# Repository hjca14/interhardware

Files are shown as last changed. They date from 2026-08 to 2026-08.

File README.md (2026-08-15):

# InterBridge Hardware

Hardware do **InterBridge**, uma ponte entre uma linha analógica compatível com
telefone convencional e um aplicativo móvel, por Wi-Fi.

## Escopo deste repositório

Este repositório concentrará o projeto eletrônico no KiCad, as bibliotecas
locais, as decisões de engenharia, as referências e, futuramente, os artefatos
de fabricação (BOM, Gerbers e dados de montagem). O firmware e o aplicativo
móvel não fazem parte deste repositório.

O projeto está em **fase inicial de pesquisa e prototipagem**. Ainda não há um
esquemático ou uma PCB aprovados. Consulte os [requisitos](docs/REQUIREMENTS.md),
a [arquitetura](docs/ARCHITECTURE.md) e as
[decisões registradas](docs/decisions/).

## Arquitetura proposta

- entrada de linha analógica em um conector **RJ11 LINE**;
- saída **RJ11 PHONE** em paralelo/pass-through para preservar o telefone ou
  interfone físico;
- proteção de linha e interface FXO/DAA, preferencialmente baseada no conjunto
  **Si3050 + Si3019**;
- módulo **ESP32-C3** para controle, processamento e conectividade Wi-Fi;
- possibilidade futura de saída por relé para instalações nas quais a abertura
  do portão usa um contato separado.

O pass-through LINE → PHONE deverá ser passivo/fail-safe sempre que a validação
elétrica da instalação permitir, de modo que o aparelho físico continue
funcionando mesmo com o InterBridge sem alimentação.

## Princípios de desenvolvimento

- A seção de telefonia será derivada de um **reference design oficial e
  validado da Skyworks para Si3050 + Si3019**, incluindo as recomendações de BOM
  e layout aplicáveis. Não serão criados valores elétricos, pinagens, footprints
  ou circuitos por suposição.
- Datasheets, reference designs e demais materiais de terceiros serão
  referenciados, e não copiados para o repositório sem que sua licença permita e
  sem necessidade clara.
- Segurança elétrica, isolamento, proteção contra surtos e os requisitos de uma
  futura homologação pela Anatel devem ser considerados desde o início, antes
  da fabricação ou conexão a uma instalação real.
- Arquivos-fonte do KiCad e bibliotecas locais devem ser versionados; saídas de
  fabricação serão geradas de forma reproduzível quando o projeto estiver
  validado.

## Estrutura

```text
kicad/                    fontes do projeto KiCad
docs/                     arquitetura, requisitos e documentação
  decisions/              Architecture Decision Records (ADRs)
  reference-designs/      notas e links para projetos de referência
libraries/
  symbols/                símbolos KiCad mantidos pelo projeto
  footprints/             footprints KiCad mantidos pelo projeto
manufacturing/
  gerbers/                 saídas para fabricação da PCB
  bom/                     listas de materiais
  assembly/                dados e instruções de montagem
```

As pastas inicialmente vazias contêm apenas `.gitkeep`. Nenhum circuito
fictício foi criado para preenchê-las.

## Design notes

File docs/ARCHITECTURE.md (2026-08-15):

# Arquitetura do sistema

## Visão de alto nível

```text
LINE RJ11
  |
  +------------------------------------------> PHONE RJ11
  |
  +--> proteção / DAA --> Si3019 <isolamento> Si3050 --> ESP32-C3
                                                        |
                                                        +--> Wi-Fi
                                                        |
                                                        +--> saída por relé (opcional/futura)
```

O diagrama representa apenas os blocos funcionais; ele **não é um circuito** e
não define pinagens, valores, footprints, componentes de proteção nem a solução
de isolamento. Esses detalhes só serão incorporados ao esquemático a partir da
documentação oficial aplicável e depois de revisão técnica.

## Caminho telefônico

O conector LINE recebe a linha analógica. Um ramo segue para a interface
telefônica FXO/DAA planejada em torno do Si3019 (lado da linha) e do Si3050 (lado
do sistema). A implementação desse ramo deverá partir do reference design
oficial da Skyworks, preservando os requisitos de isolamento, proteção, BOM e
layout que forem confirmados durante a pesquisa.

O segundo ramo conecta LINE a PHONE para que o telefone/interfone existente
permaneça disponível. O pass-through deve ser idealmente **passivo e fail-safe**:
a ausência de alimentação ou uma falha do InterBridge não deve, por si só,
interromper o uso do aparelho físico. A topologia exata e seu efeito sobre a
linha ainda precisam de validação em bancada e de uma análise de segurança.

## Controle e conectividade

O módulo ESP32-C3 será responsável pelo controle da interface telefônica e pela
comunicação via Wi-Fi com o restante do sistema. Interfaces digitais, sinais de
áudio, alimentação e firmware ainda serão definidos após a seleção definitiva
dos componentes e a validação da documentação oficial.

Uma saída por relé é uma extensão futura para instalações que disponibilizem um
contato separado de abertura de portão. Ela não faz parte do primeiro circuito
e deverá ter requisitos elétricos e de segurança próprios antes da inclusão.

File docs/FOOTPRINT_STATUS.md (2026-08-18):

# Footprint and PCB status — release-candidate audit

> Current-state summary. The historical preliminary BOM remains at `manufacturing/bom/BOM_PRELIMINARY.md`; it predates the routed PCB and is not the procurement BOM.

## Current metrics

| Metric | Result |
|---|---:|
| Physical schematic components | 65 |
| PCB footprints | 65 |
| Missing / duplicate references | 0 / 0 |
| Missing footprint assignments | 0 |
| Top / bottom components | 65 / 0 |
| Copper layers | 2 |
| Board thickness | 1.6 mm |
| Final BOM lines | 45 |
| LOCKED / EQUIVALENT_ALLOWED / VERIFY_BEFORE_ORDER lines | 16 / 29 / 0 |
| DNP | 0 |

`tools/release_inventory.py` performs the repeatable reference-parity, duplicate, footprint-presence, and side checks and writes `manufacturing/reports/COMPONENT_INVENTORY.csv`.

## Current footprint decisions

* U1 uses the project SI3019 QFN-20 footprint plus exposed pad 21; U2 uses the project SI3050 QFN-24 footprint plus exposed pad 25.
* J1 is one physical custom Amphenol RJE0166002 dual 6P6C footprint with 12 electrical pads. `_1` is LINE and `_2` is PHONE; central contacts 3/4 are RING/TIP.
* L1 uses the project VLS3012 footprint. U3 remains ESP32-C3-WROOM-02 (integrated PCB antenna), not -02U.
* The current USB connector reference is J2 and its locked MPN is GCT USB4105-GF-A-060. Older text referring to J4 is superseded; the audit did not reannotate the design.
* D1 is locked as onsemi MDB6S (1 A, 600 V) in the existing `Package_SO:TSSOP-4_4.4x5mm_P4mm` footprint. The footprint and mechanical courtyard exist. No separately validated visible 3D rendering is available for release review; assembly therefore relies on the footprint dimensions rather than 3D rendering.

## Release evidence and limitations

The PCB is routed. The user reports ERC 0 errors / 0 warnings, DRC 0 violations, and all nets routed. `kicad-cli` is absent here, so those results were not independently reproduced and manufacturing outputs were not generated. See `manufacturing/reports/RELEASE_VALIDATION.md` and `manufacturing/reports/PCB_RELEASE_AUDIT.md`.

The former count of 44 `TBD` components is no longer a blocker: those commodity parts now have electrical sourcing constraints and are `EQUIVALENT_ALLOWED`; the transistor families are similarly specified without inventing a manufacturer. There are zero component-ordering blockers.

The user reviewed the antenna keepout warning locally and visually confirmed the actual region is empty of copper, tracks, vias, and components. A final human DRC review is still required before manufacturing.

**Release candidate BOM and procurement classification are complete with zero component-ordering blockers; final human manufacturing approval is still required.**

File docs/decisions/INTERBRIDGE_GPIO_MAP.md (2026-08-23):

# InterBridge — Mapeamento de GPIO / interfaces

> Estado atual do hardware baseado no `interhardware.kicad_sch` e no
> `interhardware.kicad_pcb` da branch `main`.
> Este documento descreve o mapeamento físico previsto entre o ESP32-C3-WROOM-02 (U3) e os principais blocos da placa.

## 1. ESP32-C3 ↔ Si3050

| Componente / pino da placa | ESP32-C3 GPIO | Pad físico do módulo U3 | Função prevista | Direção vista do ESP |
|---|---:|---:|---|---|
| U2 / PCLK | GPIO0 | 18 | PCM master/input clock para o Si3050 | ESP → Si3050 |
| U2 / FSYNC | GPIO1 | 17 | PCM frame sync | ESP → Si3050 |
| U2 / SDO | GPIO2 | 16 | SPI data output do Si3050 (MISO no ESP), com pull-up externo R56 de 10 kΩ para 3,3 V | Si3050 → ESP |
| U2 / DTX | GPIO3 | 15 | PCM data transmit do Si3050 | Si3050 → ESP |
| U2 / DRX | GPIO4 | 3 | PCM data receive do Si3050 | ESP → Si3050 |
| U2 / RESET | GPIO5 | 4 | Reset do Si3050, ativo em nível baixo, com pulldown externo R54 de 10 kΩ para GND | ESP → Si3050 |
| U2 / SCLK | GPIO6 | 5 | SPI clock | ESP → Si3050 |
| U2 / SDI | GPIO7 | 6 | SPI data input do Si3050 (MOSI no ESP) | ESP → Si3050 |
| U2 / RGDT | GPIO8 | 7 | Ring detect do Si3050, saída open-drain com pull-up externo R58 de 4,7 kΩ para 3,3 V | Si3050 → ESP |
| U2 / CS | GPIO10 | 10 | SPI chip select, ativo em nível baixo | ESP → Si3050 |

GPIO9 não está ligado ao Si3050: é o pino `BOOT` do próprio ESP32-C3, reservado para modo ROM download/recuperação (ver seção 6), com pull-up externo R57 de 10 kΩ para 3,3 V.

## 2. Si3050 — sinais fora do barramento PCM/SPI

- `RGDT` (pino 6 do Si3050) está conectado ao **GPIO8** para detecção de ring. É uma saída **open-drain**, **ativa em nível baixo por padrão** (nível baixo = ring detectado), por isso depende do pull-up externo R58 (4,7 kΩ para 3,3 V) descrito na seção 1.
- `AOUT/INT` (pino 7 do Si3050) **não está conectado ao ESP**; permanece apenas no furo/pad de bancada `AOUT1`, sem GPIO associado.
- `RG`, `TGD`, `TGDE` e `SDI_THRU` continuam fora da arquitetura da Rev A (sem uso previsto).
- O polling via SPI dos registradores do Si3050 continua disponível para os demais estados/eventos que não passam por `RGDT`.

## 3. USB, botão e LED

| Componente / sinal | ESP32-C3 GPIO | Pad físico U3 | Função |
|---|---:|---:|---|
| USB D− | GPIO18 | 13 | USB 2.0 D− nativo do ESP32-C3 |
| USB D+ | GPIO19 | 14 | USB 2.0 D+ nativo do ESP32-C3 |
| SW1 / botão de setup | GPIO20 / RXD | 11 | Botão físico de setup/configuração/reset de provisioning conforme firmware |
| D2 / WS2812B DIN via R_LED1 | GPIO21 / TXD | 12 | LED RGB de status / onboarding |

## 4. Alimentação e GND

| Bloco | Alimentação | GND / domínio | Observação |
|---|---|---|---|
| J2 USB-C | VBUS 5 V | GND | Entrada principal de alimentação |
| U4 TPS62162 | 5 V em VIN | GND | Buck para 3,3 V |
| U3 ESP32-C3-WROOM-02 | +3,3 V no pad 1 | GND nos pads 9 e 19 | Domínio digital |
| U2 Si3050 | +3,3 V / alimentação digital conforme schematic | GND | Mesmo domínio digital do ESP |
| U1 Si3019 | domínio line-side | IGND | **Isolado do GND digital** |
| C1/C2 | barreira de isolamento | GND ↔ IGND | Não unir GND e IGND diretamente |

## 5. Requisitos de inicialização do firmware (RESET / modo PCM-SPI)

Esta sequência é responsabilidade do **firmware**; o hardware não a executa sozinho:

1. O firmware deve manter `RESET` (GPIO5) em nível baixo durante toda a configuração inicial do circuito.
2. `SCLK` (GPIO6) deve estar em nível **alto** no instante em que `RESET` sobe — essa condição seleciona o modo PCM/SPI do Si3050. `SCLK` em nível baixo na subida de `RESET` selecionaria o modo GCI, que não é usado nesta Rev A.
3. `PCLK` e `FSYNC` precisam estar estáveis, com relação de frequência fixa entre si, por pelo menos 10 ciclos de `PCLK` antes de o firmware liberar `RESET`.
4. Depois de liberar o reset, o firmware deve aguardar a estabilização do PLL interno do Si3050 antes de configurar os registradores via SPI.

## 6. Recuperação / programação (furos THT de bancada)

Três furos THT existem na placa para gravação/recuperação manual do ESP32-C3. Eles **não são conectores a serem montados no produto final** — são pontos de teste de bancada/fábrica:

| Furo | Sinal | Função |
|---|---|---|
| `BOOT1` | GPIO9 | Strap de boot do ESP32-C3 (modo ROM download quando em GND na subida do reset) |
| `EN1` | `/EN` | Chip enable / reset do ESP32-C3 |
| `GND1` | GND | Referência de terra |

Procedimento manual resumido para entrar em modo de gravação:

`BOOT` em GND → pulso de `EN` em GND → soltar `EN` → soltar `BOOT` → gravar via USB nativo nos GPIO18/19 (D−/D+).

Esse procedimento é usado apenas para a primeira gravação, bancada, fábrica e recuperação. Atualizações normais em campo são feitas via OTA, sem uso destes furos.

## 7. Conector J1 — LINE / PHONE

J1 é um único conector físico Amphenol `RJE0166002`, com dois jacks 6P6C.

| Jack | Contato | Função | Net atual |
|---|---:|---|---|
| LINE (`_1`) | 3 | RING | `Net-(RV1-K)` |
| LINE (`_1`) | 4 | TIP | `Net-(RV1-A)` |
| PHONE (`_2`) | 3 | RING | `Net-(RV1-K)` |
| PHONE (`_2`) | 4 | TIP | `Net-(RV1-A)` |
| LINE / PHONE | 1, 2, 5, 6 | NC | não usados |

Os contatos centrais 3/4 dos dois jacks ficam em pass-through elétrico na placa:
- `RING LINE` ↔ `RING PHONE`
- `TIP LINE` ↔ `TIP PHONE`

O DAA observa/interage com esse par através do circuito line-side, sem interromper o telefone/interfone original. Esta Rev A não tem relé, `DOOR_ACTUATE` nem qualquer forma de abertura física da linha ou da fechadura.

## 8. Resumo para firmware

```text
GPIO0   = PCLK        (PCM, ESP -> Si3050)
GPIO1   = FSYNC       (PCM, ESP -> Si3050)
GPIO2   = SDO         (SPI MISO / Si3050 -> ESP, pull-up externo 10k para 3V3)
GPIO3   = DTX         (PCM Si3050 -> ESP)
GPIO4   = DRX         (PCM ESP -> Si3050)
GPIO5   = RESET       (Si3050 reset, ativo baixo, pulldown externo R54 10k para GND)
GPIO6   = SCLK        (SPI clock, ESP -> Si3050; alto na subida de RESET = modo PCM/SPI)
GPIO7   = SDI         (SPI MOSI / ESP -> Si3050)
GPIO8   = RGDT        (Si3050 -> ESP, ring detect, open-drain ativo baixo, pull-up externo 4k7 para 3V3)
GPIO9   = BOOT        (strap de boot do ESP, modo ROM download/recuperação, pull-up externo 10k para 3V3)
GPIO10  = CS          (SPI chip select, ativo baixo)
GPIO18  = USB D-
GPIO19  = USB D+
GPIO20  = BUTTON
GPIO21  = STATUS LED (WS2812B DIN)
```

`AOUT/INT` do Si3050 não tem GPIO associado nesta Rev A; fica disponível apenas no pad de bancada `AOUT1`.

## 9. Observação de firmware

Os nomes `SDO` e `SDI` acima seguem a nomenclatura do **Si3050**, não a do ESP:
- Si3050 `SDO` = saída do Si3050 = entrada/MISO no ESP.
- Si3050 `SDI` = entrada do Si3050 = saída/MOSI no ESP.

Da mesma forma:
- `DTX` é saída PCM do Si3050.
- `DRX` é entrada PCM do Si3050.
- `RGDT` é saída open-drain do Si3050, ativa em nível baixo por padrão (requer pull-up externo, ver seção 1/2).

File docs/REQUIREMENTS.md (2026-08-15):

# Requisitos iniciais

Este documento registra requisitos de produto ainda sujeitos a refinamento. Os
itens não especificam soluções elétricas; critérios quantitativos serão
adicionados somente com referências adequadas e resultados de validação.

## Funcionais

- **RF-01 — Detecção de chamada:** detectar o sinal de ring da linha.
- **RF-02 — Controle da chamada:** atender e desligar (hangup)
  eletronicamente.
- **RF-03 — Áudio:** suportar áudio bidirecional durante uma chamada.
- **RF-04 — DTMF:** suportar os tons DTMF necessários à operação do interfone.
- **RF-05 — Aparelho em paralelo:** detectar, se tecnicamente viável, quando o
  telefone/interfone físico em paralelo estiver off-hook.
- **RF-06 — Operação sem energia:** manter o telefone/interfone físico
  utilizável quando o InterBridge estiver sem alimentação.
- **RF-07 — Conectividade:** comunicar-se com o sistema móvel por Wi-Fi.
- **RF-08 — Expansão:** permitir avaliar uma futura saída por relé para abertura
  de portão por contato separado.

## Hardware

- **RH-01:** usar conectores identificados como RJ11 LINE e RJ11 PHONE.
- **RH-02:** implementar pass-through LINE → PHONE preferencialmente passivo e
  fail-safe, condicionado à validação elétrica.
- **RH-03:** basear a seção FXO/DAA no reference design oficial selecionado; não
  definir valores, pinagens, footprints ou layout sem fonte verificável.
- **RH-04:** adotar inicialmente um módulo ESP32-C3 para controle e Wi-Fi.
- **RH-05:** manter símbolos e footprints específicos do projeto em bibliotecas
  versionadas e rastreáveis às fontes técnicas.
- **RH-06:** prever pontos de teste suficientes para validação segura dos blocos,
  a serem definidos durante o projeto do esquemático.

## Segurança

- **RS-01:** identificar as tensões, correntes, transientes e condições de falha
  aplicáveis à linha antes de dimensionar a interface.
- **RS-02:** definir isolamento e distâncias de segurança com base em normas e
  documentação técnica aplicáveis, sem pressupor valores.
- **RS-03:** incluir proteção contra surtos e eventos da linha de acordo com o
  reference design validado e os requisitos da instalação-alvo.
- **RS-04:** realizar revisão de segurança antes de conectar protótipos a uma
  linha real.
- **RS-05:** considerar desde o projeto os requisitos aplicáveis a uma futura
  homologação Anatel.
- **RS-06:** documentar limitações, riscos residuais e procedimentos seguros de
  teste.

## Fabricação

- **RM-01:** manter os fontes `.kicad_pro`, `.kicad_sch`, `.kicad_pcb` e as
  bibliotecas locais sob controle de versão.
- **RM-02:** gerar BOM, Gerbers e dados de montagem de maneira reproduzível a
  partir de uma revisão identificada do projeto.
- **RM-03:** registrar fabricante, código exato e alternativas aprovadas dos
  componentes na BOM.
- **RM-04:** executar ERC, DRC e revisão dos arquivos de fabricação antes de
  liberar uma placa.
- **RM-05:** validar disponibilidade, encapsulamento e lifecycle dos componentes
  antes da compra ou montagem.

## Ainda em investigação

- seleção definitiva entre Si3050 + Si3019, Le9641 e outras alternativas;
- disponibilidade, condições de aquisição e status de ciclo de vida dos CIs;
- compatibilidade da solução com as variações de linhas de interfone/telefone
  encontradas no Brasil;
- mecanismo e confiabilidade da detecção de off-hook do aparelho em paralelo;
- requisitos de áudio, níveis, codecs e tratamento de eco;
- requisitos detalhados de alimentação e consumo;
- topologia, classificação e interface da eventual saída por relé;
- normas técnicas, ensaios e modalidade de homologação Anatel aplicáveis;
- estratégia de testes de bancada e equipamentos necessários;
- critérios quantitativos de proteção, isolamento e layout.

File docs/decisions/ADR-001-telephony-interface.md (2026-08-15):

# ADR-001 — Interface de telefonia

- **Status:** provisoriamente aceito
- **Data:** 2026-08-15

## Contexto

O InterBridge precisa interagir com uma linha analógica compatível com telefone
convencional, detectando chamadas, controlando o estado on-hook/off-hook e
transportando áudio e DTMF. Essa interface envolve requisitos de linha,
isolamento, proteção e layout que não devem ser definidos por tentativa ou
suposição.

Nesta fase, é especialmente importante escolher uma solução que possa ser
reproduzida e revisada a partir de documentação técnica suficiente.

## Decisão

Preferir provisoriamente o conjunto **Si3050 + Si3019** para a interface FXO/DAA.
A preferência se deve à documentação pública e ao conjunto de materiais oficiais
disponíveis para avaliação — reference design, BOM, orientações de layout, placa
de avaliação (EVB) e guias relacionados.

O esquemático não será desenhado até que esses documentos sejam coletados das
fontes oficiais, revisados e transformados em requisitos rastreáveis. O projeto
não inferirá valores elétricos, pinagens ou footprints.

## Alternativas consideradas

- **Le9641:** permanece como alternativa a pesquisar, especialmente quanto a
  documentação, disponibilidade e adequação à arquitetura.
- **Outras famílias FXO/DAA:** poderão ser avaliadas com os mesmos critérios de
  documentação, segurança, disponibilidade, custo e possibilidade de validação.

## Consequências

- A primeira pesquisa e os testes de bancada serão orientados ao Si3050 +
  Si3019.
- A implementação deverá seguir o reference design oficial e suas recomendações
  aplicáveis, em vez de criar uma seção telefônica arbitrária.
- A origem e a revisão de cada documento usado deverão ser registradas em
  `docs/reference-designs/`; arquivos de terceiros não serão redistribuídos sem
  licença ou necessidade.
- A decisão **pode mudar após testes de bancada**, revisão de segurança,
  confirmação de disponibilidade ou descoberta de requisitos incompatíveis.

## Critérios para reavaliação

- resultados dos testes de ring, hook, áudio, DTMF e operação em paralelo;
- conformidade com requisitos de isolamento e proteção aplicáveis;
- qualidade e atualidade da documentação oficial;
- disponibilidade e ciclo de vida dos componentes;
- complexidade de fabricação e suporte à validação/homologação.

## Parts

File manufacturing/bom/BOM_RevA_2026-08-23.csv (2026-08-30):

Refs | Qty | Value | Manufacturer | Base_MPN | Approved_Sourcing_MPN | Description | Tolerance | Power_Rating | Voltage_Rating | Dielectric_or_Type | Package | Footprint | Procurement_Class | Notes
C1,C2 | 2 | 33pF | Murata | GA342A1XGF330JW31L |  | Safety isolation capacitor | ±5% | N/A | 250VAC | X1/Y2 safety ceramic | 1808 | Capacitor_SMD:C_1808_4520Metric | LOCKED | Isolation barrier; exact safety-certified MPN.
C3 | 1 | 3.9nF | GENERIC | GENERIC | CC1206MRX7RYBB392 | DAA high-voltage capacitor | ±20% | N/A | >=250VDC | X7R ceramic | 1206 | Capacitor_SMD:C_1206_3216Metric | EQUIVALENT_ALLOWED | EVB specifies 250V, 20%, X7R; PCB package is larger than EVB 0805.
C4 | 1 | 1uF | Panasonic | EEE-1HA010NR |  | Aluminum electrolytic capacitor | ±20% | N/A | 50V | Aluminum electrolytic | 4x5.4mm SMD | Capacitor_SMD:CP_Elec_4x5.4 | LOCKED
C5,C6,C50,C51 | 4 | 0.1uF | GENERIC | GENERIC | C0603C104M4RAC7411 | DAA bypass capacitor | ±20% | N/A | >=16VDC | X7R ceramic | 0603 | Capacitor_SMD:C_0603_1608Metric | EQUIVALENT_ALLOWED | EVB BOM: 16V X7R 20%.
C7 | 1 | 2.7nF | GENERIC | GENERIC | GCM188R71H272MA37D | DAA capacitor | ±20% | N/A | >=50VDC | X7R ceramic | 0603 | Capacitor_SMD:C_0603_1608Metric | EQUIVALENT_ALLOWED | EVB BOM: 50V X7R 20%.
C8,C9 | 2 | 680pF | Murata | GA342QR7GF681KW01L |  | Safety isolation capacitor | ±10% | N/A | 250VAC | X1/Y2 safety ceramic | 1808 | Capacitor_SMD:C_1808_4520Metric | LOCKED | Isolation barrier; exact safety-certified MPN.
C10 | 1 | 0.01uF | GENERIC | GENERIC | C0603C103M4RACTU | DAA capacitor | ±20% | N/A | >=16VDC | X7R ceramic | 0603 | Capacitor_SMD:C_0603_1608Metric | EQUIVALENT_ALLOWED | EVB BOM specifies X7R, 20%; 16V minimum sourcing constraint for low-voltage D...
C30,C31 | 2 | 120pF | GENERIC | GENERIC | HHV1206R7121K102NSLJ | DAA high-voltage capacitor | ±10% | N/A | >=250VDC | X7R ceramic | 1206 | Capacitor_SMD:C_1206_3216Metric | EQUIVALENT_ALLOWED | EVB specifies 250V, 10%, X7R; PCB package is larger than EVB 0805.
C52 | 1 | 0.1uF | GENERIC | GENERIC | 0603ZC104KAT2A | Digital decoupling capacitor | ±10% | N/A | >=10VDC | X7R ceramic | 0603 | Capacitor_SMD:C_0603_1608Metric | EQUIVALENT_ALLOWED | Digital-domain decoupling, not an EVB line-side capacitor.
C75 | 1 | 10uF | GENERIC | GENERIC | TCC0805X5R106M250FT | TPS62162 input capacitor | ±20% | N/A | >=25VDC | X7R or X5R ceramic | 0805 | Capacitor_SMD:C_0805_2012Metric | EQUIVALENT_ALLOWED | Voltage rating covers TPS62162 17V maximum input; account for DC-bias derating.
C76 | 1 | 22uF | GENERIC | GENERIC | GRM21BR60J226ME39L | TPS62162 output capacitor | ±20% | N/A | >=6.3VDC | X7R or X5R ceramic | 0805 | Capacitor_SMD:C_0805_2012Metric | EQUIVALENT_ALLOWED | 3.3V output; account for DC-bias derating.
D1 | 1 | MDB6S | onsemi | MDB6S |  | 1 A, 600 V single-phase bridge rectifier | N/A | N/A | 600 V repetiti... |  | TSSOP-4 / MDBxS | Package_SO:TSSOP-4_4.4x5mm_P4mm | LOCKED | Meets/exceeds the reference-design requirement of 0.8 A / 400 V.
D2 | 1 | WS2812B-2020 | Worldsemi | WS2812B-2020 |  | Addressable RGB LED | N/A | N/A | 5V nominal | Integrated LED/... | PLCC-4 2.0x2.0mm | LED_SMD:LED_WS2812B-2020_PLCC4_2.0x2.0mm | LOCKED
FB1,FB2,FB203,FB204 | 4 | 600 Ohm | Murata | BLM18AG601SN1 | BLM18AG601SN1D | Ferrite bead, 600 ohm at 100MHz | ±25% impedance | N/A | 50VDC | Fe... | 0603 | Inductor_SMD:L_0603_1608Metric | LOCKED
J1 | 1 | RJE0166002 | Amphenol Communications Solutions | RJE0166002 |  | Dual 6P6C right-angle jack | N/A | N/A | N/A | THT connector | Dual 6P6C right-angle THT | interbridge_telephony:AMPHENOL_RJE0166002 | LOCKED | One physical part; _1 LINE, _2 PHONE; contacts 3 RING / 4 TIP.
J2 | 1 | USB4105-GF-A-060 | GCT | USB4105-GF-A-060 |  | USB Type-C USB2 receptacle | N/A | N/A | 5V | 16-contact h... | USB-C | Connector_USB:USB_C_Receptacle_GCT_USB4105-xx-A_16P_TopMnt_Horizontal | LOCKED | Current designator is J2 (earlier documentation called it J4).
L1 | 1 | 2.2uH | TDK | VLS3012HBX-2R2M-N |  | Shielded power inductor | ±20% | Isat >=2.84A | N/A | Wirewound shiel... | VLS3012 | interbridge_telephony:IND_VLS3012HBX-2R2M-N | LOCKED
Q1,Q3 | 2 | MMBTA42 | GENERIC | MMBTA42 |  | High-voltage NPN transistor | N/A | SOT-23 dissipation; verify asse... |  |  | SOT-23 | Package_TO_SOT_SMD:SOT-23 | EQUIVALENT_ALLOWED | Reference design uses MMBTA42 family; no manufacturer frozen. Approved sourcing brand: UMW, provided ratings/package/pinout match.
Q2 | 1 | MMBTA92 | GENERIC | MMBTA92 |  | High-voltage PNP transistor | N/A | SOT-23 dissipation; verify asse... |  |  | SOT-23 | Package_TO_SOT_SMD:SOT-23 | EQUIVALENT_ALLOWED | Reference design uses MMBTA92 family; no manufacturer frozen. Approved sourcing brand: UMW, provided ratings/package/pinout match.
Q4,Q5 | 2 | MMBTA06 | GENERIC | MMBTA06 |  | NPN transistor | N/A | SOT-23 dissipation; verify assembly thermal ... |  |  | SOT-23 | Package_TO_SOT_SMD:SOT-23 | EQUIVALENT_ALLOWED | Reference design uses MMBTA06 family; no manufacturer frozen. Approved sourcing brand: UMW, provided ratings/package/pinout match.
R1 | 1 | 1.07k Ohm | GENERIC | GENERIC | AC1206FR-071K07L | Thick-film resistor | ±1% | >=0.5W | >=200V | Thick-film | 1206 | Resistor_SMD:R_1206_3216Metric | EQUIVALENT_ALLOWED | DAA EVB requires 1/2W.
R2 | 1 | 150 Ohm | GENERIC | GENERIC | RC0603FR-07150RL | Thick-film resistor | ±1% | >=0.0625W | >=25V | Thick-film | 0603 | Resistor_SMD:R_0603_1608Metric | EQUIVALENT_ALLOWED | DAA EVB requires 1/16W.
R3 | 1 | 3.65k Ohm | GENERIC | GENERIC | AC1206FR-073K65L | Thick-film resistor | ±1% | >=0.5W | >=200V | Thick-film | 1206 | Resistor_SMD:R_1206_3216Metric | EQUIVALENT_ALLOWED | DAA EVB requires 1/2W.
R4 | 1 | 2.49k Ohm | GENERIC | GENERIC | TC0650F2491T5J | Thick-film resistor | ±1% | >=0.5W | >=200V | Thick-film | 1206 | Resistor_SMD:R_1206_3216Metric | EQUIVALENT_ALLOWED | DAA EVB requires 1/2W.
R5,R6 | 2 | 100k Ohm | GENERIC | GENERIC | 0603WAJ0104T5E | Thick-film resistor | ±5% | >=0.0625W | >=25V | Thick-film | 0603 | Resistor_SMD:R_0603_1608Metric | EQUIVALENT_ALLOWED | DAA EVB requires 1/16W.
R9 | 1 | 1M Ohm | GENERIC | GENERIC | AC0603JR-071ML | Thick-film resistor | ±5% | >=0.1W | >=50V | Thick-film | 0603 | Resistor_SMD:R_0603_1608Metric | EQUIVALENT_ALLOWED | DAA bias resistor.
R10 | 1 | 536 Ohm | GENERIC | GENERIC | RC1206FR-07536RL | Thick-film resistor | ±1% | >=0.25W | >=200V | Thick-film | 1206 | Resistor_SMD:R_1206_3216Metric | EQUIVALENT_ALLOWED | DAA EVB requires 1/4W.
R11 | 1 | 73.2 Ohm | GENERIC | GENERIC | RS-06K73R2FT | Thick-film resistor | ±1% | >=0.5W | >=200V | Thick-film | 1206 | Resistor_SMD:R_1206_3216Metric | EQUIVALENT_ALLOWED | DAA EVB requires 1/2W.
R12,R13 | 2 | 56.2 Ohm | GENERIC | GENERIC | RTT0356R2FTP | Thick-film resistor | ±1% | >=0.0625W | >=25V | Thick-film | 0603 | Resistor_SMD:R_0603_1608Metric | EQUIVALENT_ALLOWED | DAA EVB requires 1/16W.
R30,R32 | 2 | 15M Ohm | GENERIC | GENERIC | HV06W4J0156T5E | Thick-film resistor | ±5% | >=0.125W | >=200V | Thick-film | 1206 | Resistor_SMD:R_1206_3216Metric | EQUIVALENT_ALLOWED | High-value DAA line-side resistor; EVB requires 1/8W.
R31,R33 | 2 | 5.1M Ohm | GENERIC | GENERIC | 1206W4J0515T5E | Thick-film resistor | ±5% | >=0.125W | >=200V | Thick-film | 1206 | Resistor_SMD:R_1206_3216Metric | EQUIVALENT_ALLOWED | High-value DAA line-side resistor; EVB requires 1/8W.
R52,R53 | 2 | 47k Ohm | GENERIC | GENERIC | 0603WAJ0473T5E | Thick-film resistor | ±5% | >=0.0625W | >=25V | Thick-film | 0603 | Resistor_SMD:R_0603_1608Metric | EQUIVALENT_ALLOWED | DAA/digital control resistors.
R54,R55,R56,R57,R_BO1 | 5 | 10k Ohm | GENERIC | GENERIC | RC0603FR-0710KL | Thick-film resistor | ±1% | >=0.1W | >=25V | Thick-film | 0603 | Resistor_SMD:R_0603_1608Metric | EQUIVALENT_ALLOWED | 10k digital bias resistors. R54 = Si3050 RESET pulldown to GND; R56 = GPIO2/SDO pull-up to 3.3V; R57 = GPIO9/BOOT pull-up to 3.3V; R55 and R_BO1 retain their existing digital bias functions.
R58 | 1 | 4.7k Ohm | GENERIC | GENERIC |  | RGDT open-drain pull-up resistor | ±1% | >=0.1W | >=25V | Thick-film | 0603 | Resistor_SMD:R_0603_1608Metric | EQUIVALENT_ALLOWED | Pull-up from Si3050 RGDT / ESP32-C3 GPIO8 to +3.3V.
R71,R72 | 2 | 5.1k Ohm | GENERIC | GENERIC | 0603WAF5101T5E | Thick-film resistor | ±1% | >=0.1W | >=25V | Thick-film | 0603 | Resistor_SMD:R_0603_1608Metric | EQUIVALENT_ALLOWED | USB-C CC resistors.
R73,R74 | 2 | 22 Ohm | GENERIC | GENERIC | 0603WAF220JT5E | Thick-film resistor | ±1% | >=0.1W | >=25V | Thick-film | 0603 | Resistor_SMD:R_0603_1608Metric | EQUIVALENT_ALLOWED | USB data series resistors.
R75 | 1 | 100k Ohm | GENERIC | GENERIC | CQ03WAF1003T5E | Thick-film resistor | ±1% | >=0.1W | >=25V | Thick-film | 0603 | Resistor_SMD:R_0603_1608Metric | EQUIVALENT_ALLOWED | TPS62162 control/bias resistor.
RV1 | 1 | P3100SBL | Littelfuse | P3100SBL | P3100SBLRP | Bidirectional SIDACtor | N/A | N/A | 275V standoff | SIDACtor, not... | DO-214AA / SMB | Diode_SMD:D_SMB | LOCKED
SW1 | 1 | B3U-1000P | Omron | B3U-1000P |  | Normally-open tactile switch | N/A | N/A | N/A | Momentary SPST-NO | SMD | Button_Switch_SMD:SW_SPST_B3U-1000P | LOCKED
U1 | 1 | SI3019-F-FM | Skyworks Solutions | SI3019-F-FM |  | Line-side DAA IC | N/A | N/A | Per datasheet | QFN-20 + exposed... | QFN-20-1EP | interbridge_telephony:3019-F-FM-QFN40P300X300X90-21N | LOCKED | Exposed electrical pad 21 maps to IGND.
U2 | 1 | SI3050-E1-FM | Skyworks Solutions | SI3050-E1-FM |  | System-side DAA IC | N/A | N/A | Per datasheet | QFN-24 + expo... | QFN-24-1EP | interbridge_telephony:3050-E1-FM-QFN50P400X400X80-25N | LOCKED | Exposed electrical pad 25 maps to GND.
U3 | 1 | ESP32-C3-WROOM-02 | Espressif Systems | ESP32-C3-WROOM-02 | ESP32-C3-WROOM-02-N4 OR ESP32-C3-WROOM-02-H4 | Wi-Fi/BLE module with PCB antenna | N/A | N/A | 3.0-3.6V『... |  | Module | RF_Module:ESP32-C3-WROOM-02 | LOCKED | 4 MB flash, integrated PCB antenna. N4 and H4 are both approved; do not use -02U.
U4 | 1 | TPS62162DSG | Texas Instruments | TPS62162DSG | TPS62162DSGT | 3.3V 1A step-down converter | N/A | N/A | 3-17V input | WSON-8 ... | WSON-8-1EP DSG | Package_SON:Texas_DSG0008A_WSON-8-1EP_2x2mm_P0.5mm_EP0.9x1.6... | LOCKED
Z1 | 1 | 43V | onsemi | MMSZ43T1G |  | 43V Zener diode | ±5% | 500mW | 43V nominal | Zener | SOD-123 | Diode_SMD:D_SOD-123 | LOCKED
C_LED1 | 1 | 0.1uF | GENERIC | GENERIC | 0603ZC104KAT2A | LED local decoupling capacitor | ±10% | N/A | >=10VDC | X7R ceramic | 0603 | Capacitor_SMD:C_0603_1608Metric | EQUIVALENT_ALLOWED
R_LED1 | 1 | 330 Ohm | GENERIC | GENERIC | 0603WAF3300T5E | Thick-film resistor | ±1% | >=0.1W | >=25V | Thick-film | 0603 | Resistor_SMD:R_0603_1608Metric | EQUIVALENT_ALLOWED | LED series resistor.

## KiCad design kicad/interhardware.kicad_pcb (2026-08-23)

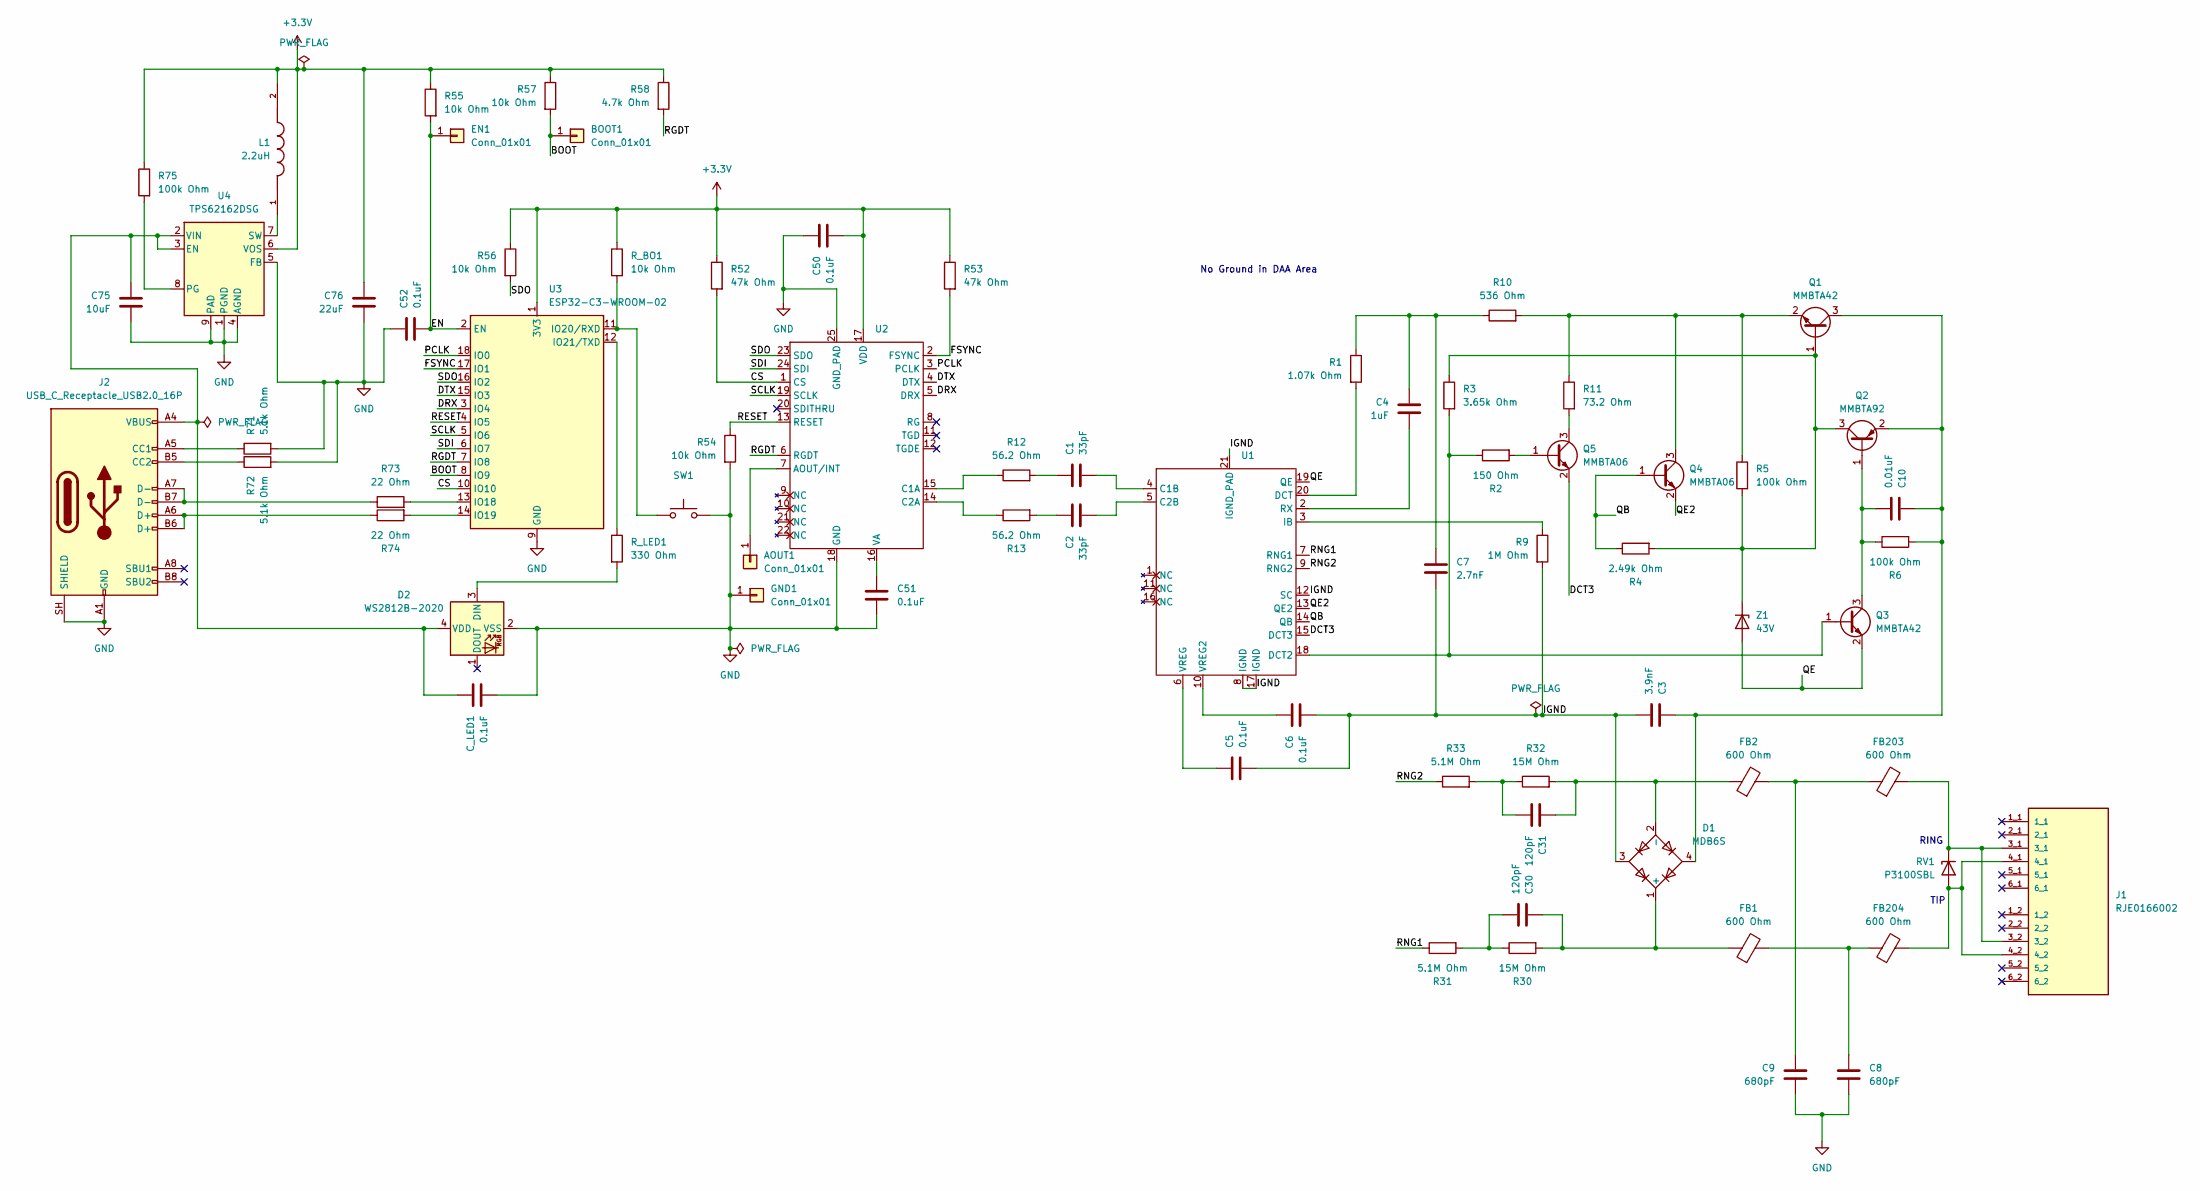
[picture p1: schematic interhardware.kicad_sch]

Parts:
AOUT1: Conn_01x01; PinHeader_1x01_P2.54mm_Vertical
BOOT1: Conn_01x01; PinHeader_1x01_P2.54mm_Vertical
C1, C2: 33pF; C_1808_4520Metric; MPN GA342A1XGF330JW31L
C3: 3.9nF; C_1206_3216Metric; MPN GENERIC
C4: 1uF; CP_Elec_4x5.4; MPN EEE-1HA010NR
C5, C6, C50, C51, C52: 0.1uF; C_0603_1608Metric; MPN GENERIC
C7: 2.7nF; C_0603_1608Metric; MPN GENERIC
C8, C9: 680pF; C_1808_4520Metric; MPN GA342QR7GF681KW01L
C10: 0.01uF; C_0603_1608Metric; MPN GENERIC
C30, C31: 120pF; C_1206_3216Metric; MPN GENERIC
C75: 10uF; C_0805_2012Metric; MPN GENERIC
C76: 22uF; C_0805_2012Metric; MPN GENERIC
C_LED1: 0.1uF; C_0603_1608Metric; MPN GENERIC
D1: MDB6S; TSSOP-4_4.4x5mm_P4mm; MPN MDB6S
D2: WS2812B-2020; LED_WS2812B-2020_PLCC4_2.0x2.0mm; MPN WS2812B-2020
EN1: Conn_01x01; PinHeader_1x01_P2.54mm_Vertical
FB1, FB2, FB203, FB204: 600 Ohm; L_0603_1608Metric; MPN BLM18AG601SN1
GND1: Conn_01x01; PinHeader_1x01_P2.54mm_Vertical
J1: RJE0166002; AMPHENOL_RJE0166002; PARTREV A
J2: USB_C_Receptacle_USB2.0_16P; USB_C_Receptacle_GCT_USB4105-xx-A_16P_TopMnt_Horizontal; MPN USB4105-GF-A-060
L1: 2.2uH; IND_VLS3012HBX-2R2M-N; PARTREV N/A
Q1, Q3: MMBTA42; SOT-23; MPN MMBTA42
Q2: MMBTA92; SOT-23; MPN MMBTA92
Q4, Q5: MMBTA06; SOT-23; MPN MMBTA06
R1: 1.07k Ohm; R_1206_3216Metric; MPN GENERIC
R2: 150 Ohm; R_0603_1608Metric; MPN GENERIC
R3: 3.65k Ohm; R_1206_3216Metric; MPN GENERIC
R4: 2.49k Ohm; R_1206_3216Metric; MPN GENERIC
R5, R6, R75: 100k Ohm; R_0603_1608Metric; MPN GENERIC
R9: 1M Ohm; R_0603_1608Metric; MPN GENERIC
R10: 536 Ohm; R_1206_3216Metric; MPN GENERIC
R11: 73.2 Ohm; R_1206_3216Metric; MPN GENERIC
R12, R13: 56.2 Ohm; R_0603_1608Metric; MPN GENERIC
R30, R32: 15M Ohm; R_1206_3216Metric; MPN GENERIC
R31, R33: 5.1M Ohm; R_1206_3216Metric; MPN GENERIC
R52, R53: 47k Ohm; R_0603_1608Metric; MPN GENERIC
R54, R55, R56, R57: 10k Ohm; R_0603_1608Metric; MPN GENERIC
R58: 4.7k Ohm; R_0603_1608Metric; MPN GENERIC
R71, R72: 5.1k Ohm; R_0603_1608Metric; MPN GENERIC
R73, R74: 22 Ohm; R_0603_1608Metric; MPN GENERIC
RV1: P3100SBL; D_SMB; MPN P3100SBL
R_BO1: 10k Ohm; R_0603_1608Metric; MPN GENERIC
R_LED1: 330 Ohm; R_0603_1608Metric; MPN GENERIC
SW1: B3U-1000P; SW_SPST_B3U-1000P; MPN B3U-1000P
U1: 3019-F-FM-QFN40P300X300X90-21N
U2: 3050-E1-FM-QFN50P400X400X80-25N
U3: ESP32-C3-WROOM-02; MPN ESP32-C3-WROOM-02
U4: TPS62162DSG; Texas_DSG0008A_WSON-8-1EP_2x2mm_P0.5mm_EP0.9x1.6mm_ThermalV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; MPN TPS62162DSG
Z1: 43V; D_SOD-123; MPN MMSZ43T1G

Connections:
+3.3V: C50.2, C76.1, L1.2, R52.1, R53.1, R55.1, R56.1, R57.1, R58.1, R75.1, R_BO1.1, U2.17 (VDD), U3.1 (3V3), U4.6 (VOS)
/BOOT: BOOT1.1 (Pin_1_1), R57.2, U3.8 (IO9)
/CS: R52.2, U2.1 (CS), U3.10 (IO10)
/DCT3: Q5.2 (E), U1.15 (DCT3)
/DRX: U2.5 (DRX), U3.3 (IO4)
/DTX: U2.4 (DTX), U3.15 (IO3)
/EN: C52.2, EN1.1 (Pin_1_1), R55.2, U3.2 (EN)
/FSYNC: R53.2, U2.2 (FSYNC), U3.17 (IO1)
/IGND: C3.2, C5.2, C6.2, C7.2, D1.3, R9.2, U1.8 (IGND), U1.12 (SC), U1.17 (IGND), U1.21 (IGND_PAD)
/PCLK: U2.3 (PCLK), U3.18 (IO0)
/QB: Q4.1 (B), R4.1, U1.14 (QB)
/QE: Q3.2 (E), U1.19 (QE), Z1.2 (A)
/QE2: Q4.2 (E), U1.13 (QE2)
/RESET: R54.1, U2.13 (RESET), U3.4 (IO5)
/RGDT: R58.2, U2.6 (RGDT), U3.7 (IO8)
/RNG1: R31.1, U1.7 (RNG1)
/RNG2: R33.1, U1.9 (RNG2)
/SCLK: U2.19 (SCLK), U3.5 (IO6)
/SDI: U2.24 (SDI), U3.6 (IO7)
/SDO: R56.2, U2.23 (SDO), U3.16 (IO2)
GND: C8.2, C9.2, C50.1, C51.2, C52.1, C75.2, C76.2, C_LED1.2, D2.2 (VSS), GND1.1 (Pin_1_1), J2.A1 (GND), J2.A12 (GND), J2.B1 (GND), J2.B12 (GND), J2.SH (SHIELD), R54.2, R71.2, R72.2, SW1.2, U2.18 (GND), U2.25 (GND_PAD), U3.9 (GND), U3.19 (GND), U4.1 (PGND), U4.4 (AGND), U4.5 (FB), U4.9 (PAD)
unnamed: AOUT1.1 (Pin_1_1), U2.7 (AOUT/INT)
unnamed: C1.1, R12.2
unnamed: C2.1, R13.2
unnamed: C4.1, C7.1, R1.1, R10.1
unnamed: C8.1, FB1.2, FB204.1
unnamed: C9.1, FB2.2, FB203.1
unnamed: C30.2, R30.1, R31.2
unnamed: C31.2, R32.1, R33.2
unnamed: C30.1, D1.1 (+), FB1.1, R30.2
unnamed: C31.1, D1.2 (-), FB2.1, R32.2
unnamed: D2.3 (DIN), R_LED1.2
unnamed: C75.1, C_LED1.1, D2.4 (VDD), J2.A4 (VBUS), J2.A9 (VBUS), J2.B4 (VBUS), J2.B9 (VBUS), U4.2 (VIN), U4.3 (EN)
unnamed: J2.A5 (CC1), R71.1
unnamed: J2.B5 (CC2), R72.1
unnamed: J2.A6 (D+), J2.B6 (D+), R74.1
unnamed: J2.A7 (D-), J2.B7 (D-), R73.1
unnamed: Q1.1 (B), Q2.3 (C), R3.1, R4.2, R5.2, Z1.1 (K)
unnamed: C3.1, C10.1, D1.4, Q1.3 (C), Q2.2 (E), R6.2
unnamed: Q1.2 (E), Q4.3 (C), R5.1, R10.2, R11.1
unnamed: C10.2, Q2.1 (B), Q3.3 (C), R6.1
unnamed: Q3.1 (B), R2.1, R3.2, U1.18 (DCT2)
unnamed: Q5.1 (B), R2.2
unnamed: Q5.3 (C), R11.2
unnamed: FB204.2, J1.4_1, J1.4_2, RV1.2 (A)
unnamed: FB203.2, J1.3_1, J1.3_2, RV1.1 (K)
unnamed: C1.2, U1.4 (C1B)
unnamed: C2.2, U1.5 (C2B)
unnamed: R1.2, U1.20 (DCT)
unnamed: R9.1, U1.3 (IB)
unnamed: C4.2, U1.2 (RX)
unnamed: C6.1, U1.10 (VREG2)
unnamed: C5.1, U1.6 (VREG)
unnamed: R12.1, U2.15 (C1A)
unnamed: R13.1, U2.14 (C2A)
unnamed: C51.1, U2.16 (VA)
unnamed: R73.2, U3.13 (IO18)
unnamed: R74.2, U3.14 (IO19)
unnamed: R_BO1.2, SW1.1, U3.11 (IO20/RXD)
unnamed: R_LED1.1, U3.12 (IO21/TXD)
unnamed: R75.2, U4.8 (PG)
unnamed: L1.1, U4.7 (SW)

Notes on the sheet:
RING
No Ground in DAA Area
TIP

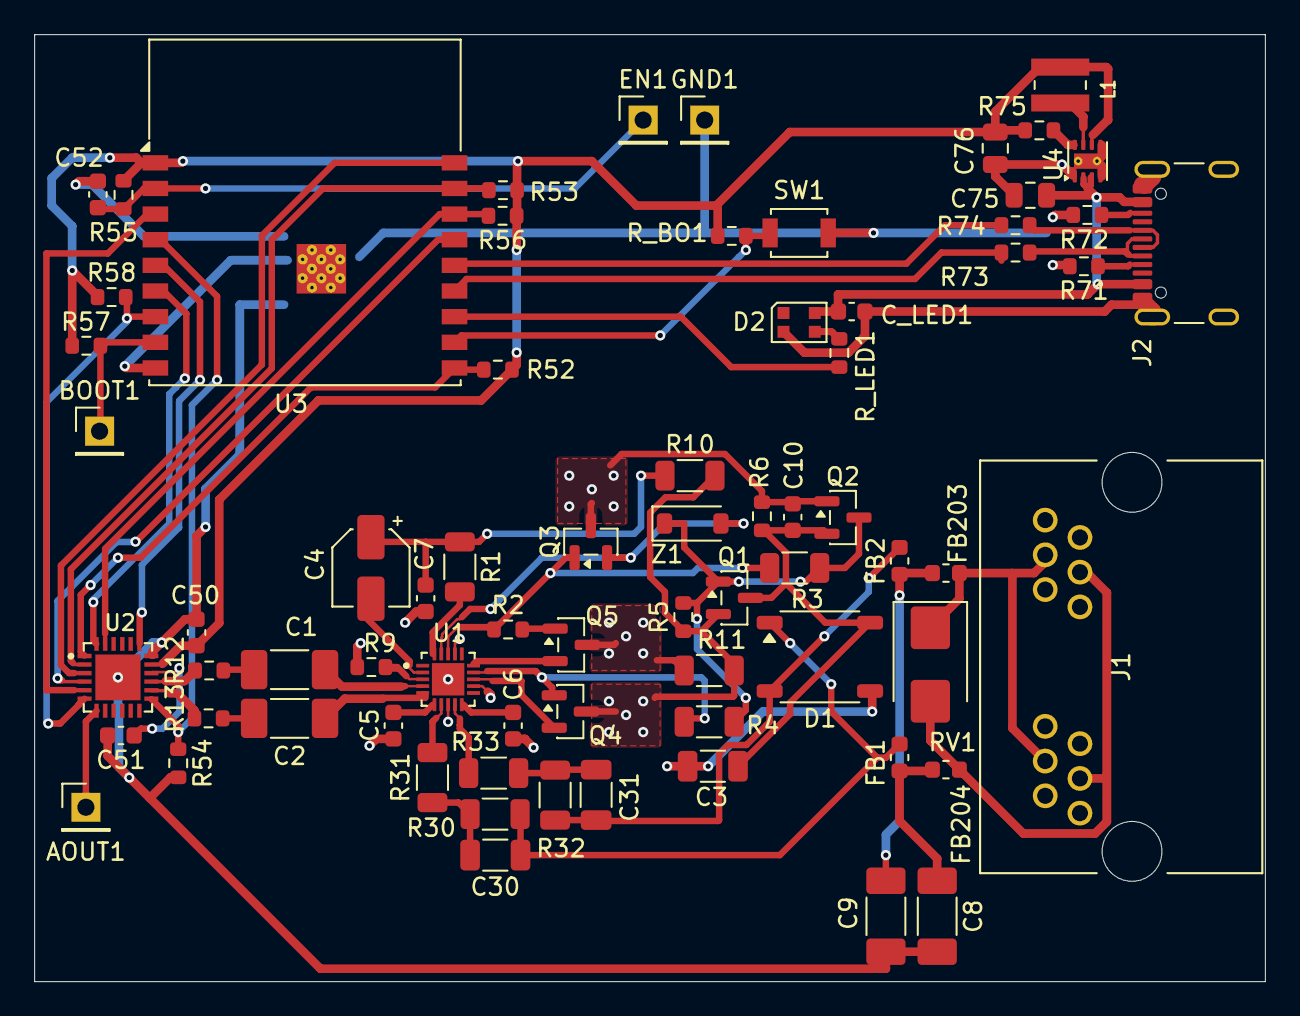
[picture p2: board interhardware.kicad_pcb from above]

Board: 2 copper layers, 72.0 x 55.4 mm, 72 parts (0 on the bottom side), 62 nets.

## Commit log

2026-08-15 docs base
    [interhardware.kicad_pcb, interhardware.kicad_sch]
2026-08-15 feat(kicad): transcribe Si3050 EVB page 3 schematic
    [interhardware.kicad_sch]
2026-08-16 esp e usb
    [interhardware.kicad_sch]
2026-08-16 terminando schematic
    [interhardware.kicad_sch]
2026-08-16 docs: inventory schematic BOM and footprints
2026-08-16 edit esp
    [interhardware.kicad_sch]
2026-08-16 footprints iniciais
    [interhardware.kicad_sch]
2026-08-16 todos os footprints
    [interhardware.kicad_sch]
2026-08-16 audit schematic footprints and component metadata
    [interhardware.kicad_sch]
2026-08-16 trocando os RJ11
    [interhardware.kicad_sch]
2026-08-16 rj11 existente moderno duplo
    [interhardware.kicad_sch]
2026-08-16 finalize schematic components for PCB transfer
    [interhardware.kicad_sch]
2026-08-17 ajustando erros
    [interhardware.kicad_sch]
2026-08-17 erros ERC Corrigidos
    [interhardware.kicad_sch]
2026-08-18 pcb completa
    [interhardware.kicad_pcb, interhardware.kicad_sch]
2026-08-18 edit pra deixar 100%
    [interhardware.kicad_pcb]
2026-08-18 document release candidate validation workflow
    [BOM_FINAL.csv, COMPONENT_INVENTORY.csv]
2026-08-18 ajuste do D1
    [interhardware.kicad_pcb, interhardware.kicad_sch]
2026-08-18 finalize MDB6S procurement release artifacts
    [BOM_FINAL.csv, COMPONENT_INVENTORY.csv, interhardware.kicad_pcb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]
2026-08-20 caminho relativo
    [interhardware-B_Cu.gbr, interhardware-B_Mask.gbr, interhardware-B_Paste.gbr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]
2026-08-23 nova forma e usando gpio8
    [interhardware.kicad_pcb, interhardware.kicad_sch]
2026-08-23 maisum pad
    [interhardware-B_Cu.gbr, interhardware-B_Mask.gbr, interhardware-Edge_Cuts.gbr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]
2026-08-23 ajuste chek-up
    [interhardware-B_Cu.gbr, interhardware-B_Mask.gbr, interhardware-Edge_Cuts.gbr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]
2026-08-30 ajustando manufacturing
    [BOM_FINAL.csv, BOM_RevA_2026-08-23.csv, COMPONENT_INVENTORY.csv]
